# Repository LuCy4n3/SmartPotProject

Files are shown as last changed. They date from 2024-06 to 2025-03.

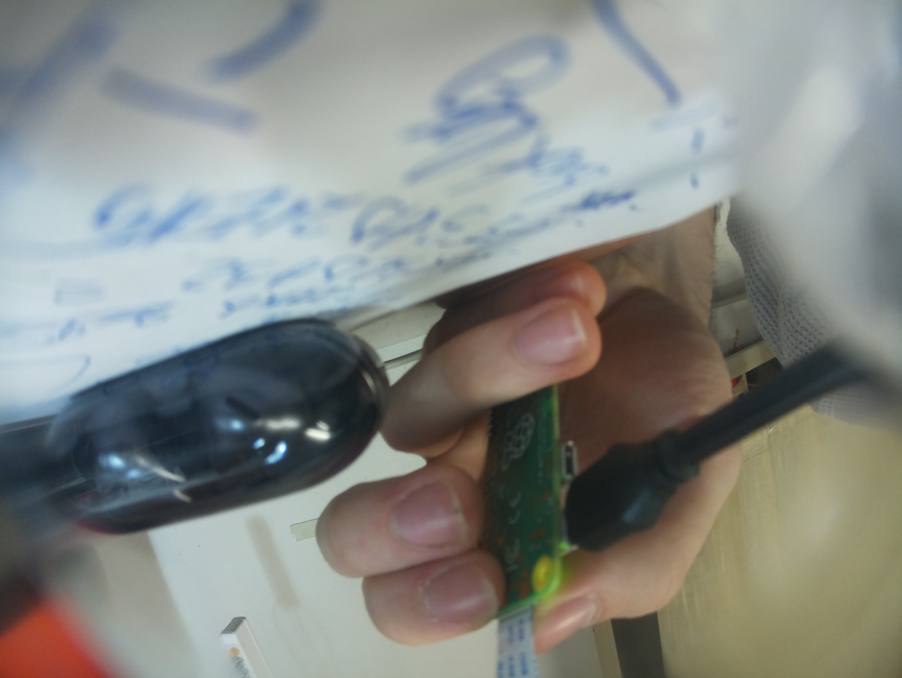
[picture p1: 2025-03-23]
SQLserverFinale/SQLserverFinale/wwwroot/images/test.jpg

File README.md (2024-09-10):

This are all the apps required, except Programmer I didn't code that, for the SmartPot PCB too work with the app GreenGrowApp. For this apps to run locally it is required to change the launchSettings file on both .NET apps and changing the URLs in the android app.

This is the link to proof of concept video: https://www.youtube.com/watch?v=sH559vDkE20&t=21s&ab_channel=RaulSimonca

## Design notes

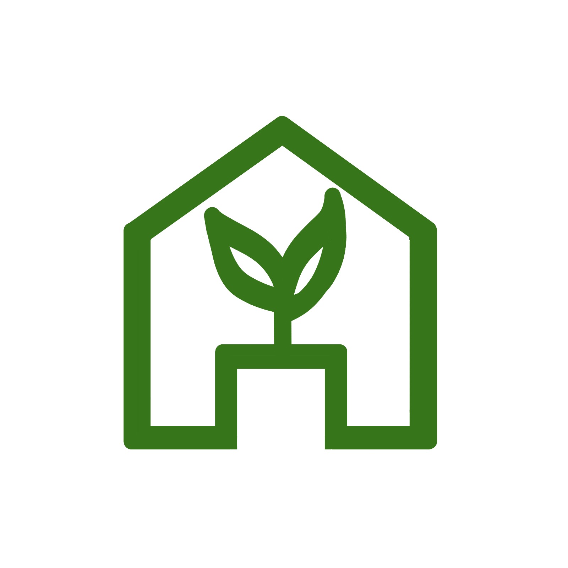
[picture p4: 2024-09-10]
pictApp.jpg

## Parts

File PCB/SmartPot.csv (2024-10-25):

Reference | Value | Datasheet | Footprint | Qty | DNP
C1,C4,Cbst1 | 100nF | ~ | -- mixed values -- | 3
C2 | 0.1uF | ~ | Capacitor_SMD:C_1206_3216Metric | 1
C3,Cin1,Cin2 | 10uF | ~ | -- mixed values -- | 3
C5 | 1uF | ~ | Capacitor_SMD:C_1206_3216Metric | 1
Cout1 | 47uF | ~ | Capacitor_SMD:C_1206_3216Metric_Pad1.33x1.80mm_HandSolder | 1
D1 | SM712_SOT23 | https://www.littelfuse.com/~/media/electronics/datasheets/tvs_diode_arrays/littelfuse_tvs_diode_array_sm712_datasheet.pdf.pdf | Package_TO_SOT_SMD:SOT-23 | 1
D2 | 1N4148W | https://www.vishay.com/docs/85748/1n4148w.pdf | Diode_SMD:D_SOD-123 | 1
D3 | LED | ~ | LED_THT:LED_D3.0mm_FlatTop | 1
F1 | Fuse | ~ | Fuse:Fuse_1206_3216Metric | 1
J1,J2 | Screw_Terminal_01x02 | ~ | TerminalBlock:TerminalBlock_bornier-2_P5.08mm | 2
J3,J5 | Conn_01x03_Pin | ~ | Connector_PinHeader_2.54mm:PinHeader_1x03_P2.54mm_Vertical | 2
J4 | Barrel_Jack_MountingPin | ~ | Connector_BarrelJack:BarrelJack_Kycon_KLDX-0202-xC_Horizontal | 1
J6 | Conn_01x04_Pin | ~ | Connector_PinHeader_2.54mm:PinHeader_1x04_P2.54mm_Vertical | 1
J7,J8 | Conn_01x02_Pin | ~ | Connector_PinHeader_2.54mm:PinHeader_1x02_P2.54mm_Vertical | 2
J9 | Screw_Terminal_01x04 | ~ | TerminalBlock_Altech:Altech_AK100_1x04_P5.00mm | 1
K1 | AWHSH112DM00G |  | Relay_THT:AWHSH112DM00G | 1
L1 | 4.7uH | ~ | Inductor_SMD:L_6.8x6.8_H3 | 1
Q1 | SSM3J352F_LF |  | Package_S-Mini:S-MINI_TOS | 1
R1,R2,R12,Rfbb1 | 10kOhm | ~ | -- mixed values -- | 4
R3,R4 | 10Ohm | ~ | Resistor_SMD:R_1210_3225Metric | 2
R5 | 120 | ~ | Resistor_SMD:R_1206_3216Metric | 1
R6,R7,R8,R9 | R_Photo | ~ | OptoDevice:R_LDR_4.9x4.2mm_P2.54mm_Vertical | 4
R10 | 10kohm | ~ | Resistor_SMD:R_1206_3216Metric_Pad1.30x1.75mm_HandSolder | 1
R11,R13,Rfbt1 | 56.2kOhm | ~ | -- mixed values -- | 3
R14,R15 | 20kOhm | ~ | Resistor_SMD:R_1206_3216Metric_Pad1.30x1.75mm_HandSolder | 2
R16 | 250-400 Ohm | ~ | Resistor_SMD:R_1206_3216Metric | 1
U1 | TPS561208DDCT |  | Converter_DCDC:SOT95P280X110-6N | 1
U2 | ADC084S021CIMM/NOPB | ADC084S021CIMM/NOPB | Package_SO:VSSOP-10_3x3mm_P0.5mm | 1
U3 | ULN2003A | http://www.ti.com/lit/ds/symlink/uln2003a.pdf | Package_SO:SOIC-16W_5.3x10.2mm_P1.27mm | 1
U4 | THVD1400D | https://www.ti.com/lit/ds/symlink/thvd1420.pdf | Package_SO:SOIC-8_3.9x4.9mm_P1.27mm | 1
U5 | AVR32DA32x-xPT | https://ww1.microchip.com/downloads/en/DeviceDoc/AVR32DA28-32-48-Data-Sheet-40002228B.pdf | Package_QFP:TQFP-32_7x7mm_P0.8mm | 1
U6 | SHT31A-DIS | https://www.sensirion.com/fileadmin/user_upload/customers/sensirion/Dokumente/2_Humidity_Sensors/Datasheets/Sensirion_Humidity_Sensors_SHT3xA_Datasheet.pdf | Sensor_Humidity:Sensirion_DFN-8-1EP_2.5x2.5mm_P0.5mm_EP1.1x1.7mm | 1
U7,U8 | ~ |  | -- mixed values -- | 2

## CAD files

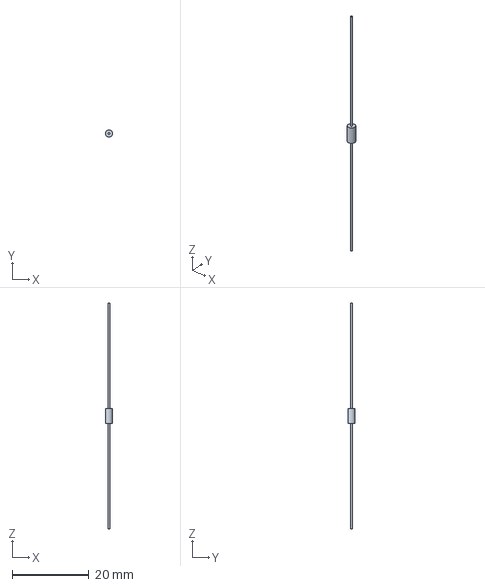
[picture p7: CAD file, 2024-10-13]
PCB/Components/1N4150/1N4150--3DModel-STEP-711646.STEP
1.90 x 1.90 x 58.9 mm

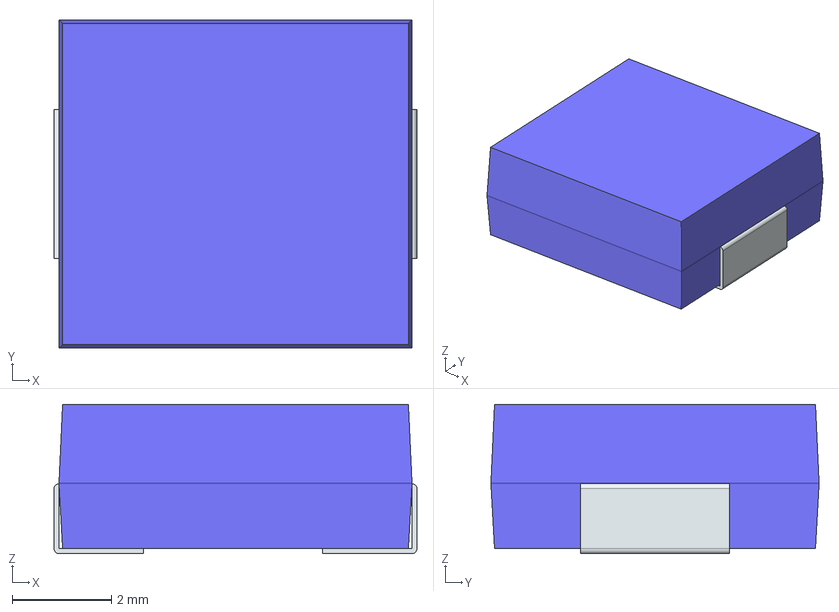
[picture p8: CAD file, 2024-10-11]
PCB/Components/Inductor/SRP7028CC-6R8M.stp
7.30 x 6.60 x 3.00 mm
FilletPin1
FilletPin2

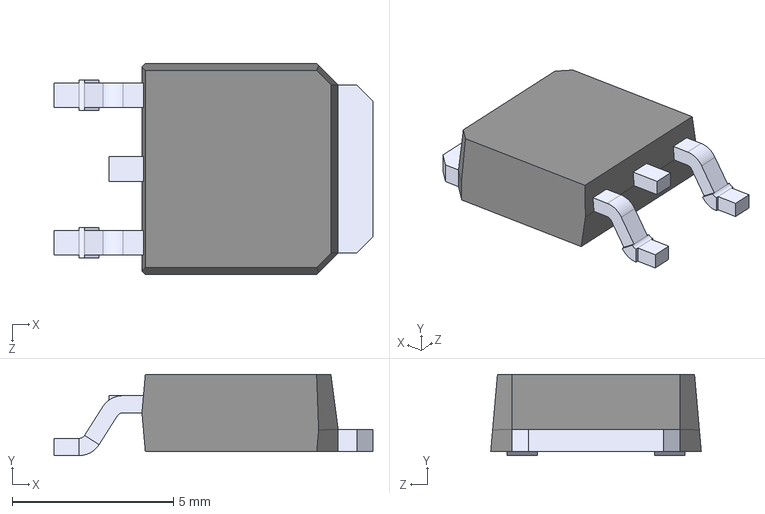
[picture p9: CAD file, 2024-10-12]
PCB/Components/IRFR5505/IRFR5505.step
9.91 x 2.52 x 6.54 mm

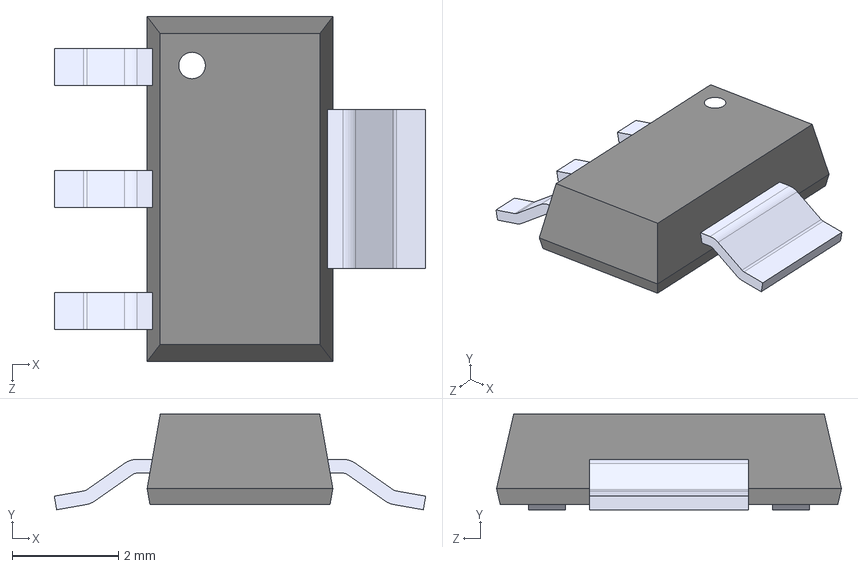
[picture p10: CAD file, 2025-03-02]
PCB/Components/LD1117S50TR/LD1117S50TR.step
7.00 x 1.80 x 6.50 mm

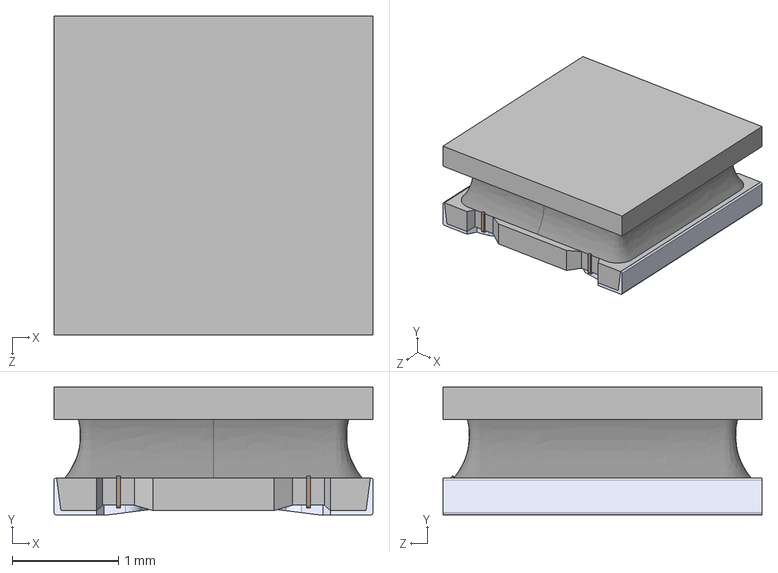
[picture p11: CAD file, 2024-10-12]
PCB/Components/LIB_SRP7028CC-6R8M/LQH3NPNR68NJRK.STEP
3.00 x 1.20 x 3.00 mm

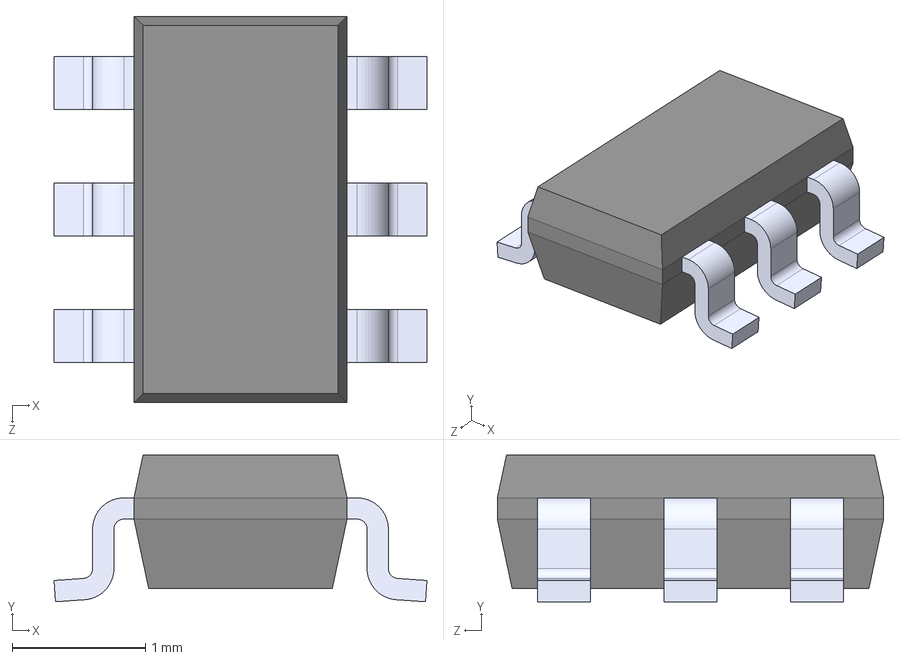
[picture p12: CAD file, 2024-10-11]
PCB/Components/TPS561208DDCT/TPS561208DDCT.step
2.80 x 1.10 x 2.90 mm

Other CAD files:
PCB/Components/LIB_SRP7028CC-6R8M/SRP7028CC-6R8M/Allegro/indpm7366x300n.psm
PCB/Components/LIB_SRP7028CC-6R8M/SRP7028CC-6R8M/DEHDL/srp7028cc_6r8m/chips/chips.prt

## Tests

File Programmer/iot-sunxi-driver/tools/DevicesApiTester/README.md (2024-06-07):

# DeviceApiTester

DeviceApiTester is a sample application primarily for testing the GPIO drivers and surrounding infrastructure.  After publishing the app to a target device, simply run `DeviceApiTester` to see the command line syntax.

One notable difference between the samples and real-world usage is that, because this sample allows for changing the GPIO driver from the command line, the base `GpioCommand` class has the `CreateGpioController` method. In practice, though, you would simply create the `GpioController` directly:

```csharp
using (var gpio = new GpioController())
{
    ...
}
```

Similarly, the same note applies to the SPI, I2C, and PWM test commands.

To simplify the command line parsing and adding new command, this application uses the
[CommandLineParser](https://github.com/commandlineparser/commandline) package. This simple parsing framework automatically creates help text based on attributes of the classes in the `Commands` folder, such as the `GpioBlinkLed` class.

Each of the commands has an `ExecuteAsync` or `Execute` method at the top of the class, which is where the sample usage is actually demonstrated. The automatic properties of the class represent options for the command, which are set by the command line parsing framework. The attributes on the command and its properties are used to setup the command line.

## Examples

1. See a list of all commands:<br/>
`DeviceApiTester help`

2. Show the `gpio-button-event` command's syntax:<br/>
`DeviceApiTester help gpio-button-event`

3. Run the command with required parameters:<br/>
`DeviceApiTester gpio-button-event --button-pin 5 --led-pin 6`

4. Run the command with many optional parameters:<br/>
`DeviceApiTester gpio-button-event --scheme Board --button-pin 29 --pressed-value Falling --led-pin 31 --on-value Low --driver RPi3`

5. Run the command with many optional parameters using single-characters options:<br/>
`DeviceApiTester gpio-button-event -s Board -b 29 -p Falling -l 31 --on-value Low -d RPi3`

## Adding Additional Commands

1. Derive a new class from one of the protocol base command classes, e.g., `GpioCommand`, `I2cCommand`, `SpiCommand`.  Deriving from one of these classes automatically gives your command the switches necessary to setup that type of connection.

    ```csharp
    namespace DeviceApiTester.Commands.I2c
    {
        public class MyCommand : I2cCommand
        {
        }
    }
    ```
    
    - It's easiest to begin by copying one of the existing commands.
    - Keep the new command class within the folder for connection type:<br/>
      `Commands/Gpio`, `Commands/I2c`, `Commands/Spi`.

2. Add or modify the `Verb` attribute to describe the command:
    ```csharp
    [Verb("i2c-my-command", HelpText = "This command does something with an I2C connection.")]
    ```
    - Prefix the command's verb with its connection type: `gpio-`, `i2c-`, `spi-`  

3. Implement either the `ICommandVerb` or `ICommandVerbAsync` interface on your command class:
    ```csharp
    public class MyCommand : I2cCommand, ICommandVerb
    {
        public int Execute()
        {
            Console.WriteLine($"BusId={BusId}, DeviceAddress={DeviceAddress}");
            return 0;
        }
    }
    ```
    or
    ```csharp
    public class MyCommand : I2cCommand, ICommandVerbAsync
    {
        public async Task<int> ExecuteAsync()
        {
            Console.WriteLine($"BusId={BusId}, DeviceAddress={DeviceAddress}");
            await Task.Delay(500);
            return 0;
        }
    }
    ```

4. Add automatic properties for command options:
    ```csharp
    [Option('c', "cool-option", HelpText = "A cool option argument", Required = false, Default = 0)]
    public int CoolOption { get; set; }
    ```

5. Use the properties in your execution:
    ```csharp
    public int Execute()
    {
        Console.WriteLine($"CoolOption={CoolOption}, BusId={BusId}, DeviceAddress={DeviceAddress}");
        ...
    }
    ```

6. Deploy and run:
    ```
    DeviceApiTester help
    DeviceApiTester help i2c-my-command
    DeviceApiTester i2c-my-command --cool-option 42
    ```

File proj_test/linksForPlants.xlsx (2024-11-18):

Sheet: completed
Daylilies | https://garden.org/plants/browse/plants/children/181473/
Irises | https://garden.org/plants/browse/plants/children/181474/
Roses | https://garden.org/plants/browse/plants/children/181506/
Sempervivum | https://garden.org/plants/browse/plants/children/186377/
Lilies | https://garden.org/plants/browse/plants/children/77555/
Hostas | https://garden.org/plants/browse/plants/children/181510/
Dahlias | https://garden.org/plants/browse/plants/children/76165/
Peonies | https://garden.org/plants/browse/plants/children/530825/
Daffodils | https://garden.org/plants/browse/plants/children/77916/
Tomatoes | https://garden.org/plants/browse/plants/children/77653/
Abelias | https://garden.org/plants/browse/plants/children/242735/
Abutilons | https://garden.org/plants/browse/plants/children/242733/
Adeniums | https://garden.org/plants/browse/plants/children/242253/
Aeoniums | https://garden.org/plants/browse/plants/children/649201/
Agapanthus | https://garden.org/plants/browse/plants/children/75143/
Agaves | https://garden.org/plants/browse/plants/children/242254/
Aglaonemas | https://garden.org/plants/browse/plants/children/71544/
Air Plants | https://garden.org/plants/browse/plants/children/232959/
Aloes | https://garden.org/plants/browse/plants/children/242252/
Amaryllis | https://garden.org/plants/browse/plants/children/76980/
Amorphophallus | https://garden.org/plants/browse/plants/children/243338/
Angel's Trumpets | https://garden.org/plants/browse/plants/children/236057/
Anise Hyssops | https://garden.org/plants/browse/plants/children/242700/
Anthuriums | https://garden.org/plants/browse/plants/children/538637/
Apples | https://garden.org/plants/browse/plants/children/86564/
Apricots | https://garden.org/plants/browse/plants/children/114689/
Arborvitaes | https://garden.org/plants/browse/plants/children/710373/
Arisaemas | https://garden.org/plants/browse/plants/children/528695/
Artichokes | https://garden.org/plants/browse/plants/children/87062/
Arums | https://garden.org/plants/browse/plants/children/641388/
Asparagus | https://garden.org/plants/browse/plants/children/86226/
Asters | https://garden.org/plants/browse/plants/children/232412/
Astilbes | https://garden.org/plants/browse/plants/children/242590/
Astragaluses | https://garden.org/plants/browse/plants/children/536504/
Baby's Breaths | https://garden.org/plants/browse/plants/children/126348/
Bananas | https://garden.org/plants/browse/plants/children/533137/
Baptisias | https://garden.org/plants/browse/plants/children/536505/
Barberries | https://garden.org/plants/browse/plants/children/240127/
Basils | https://garden.org/plants/browse/plants/children/588177/
Beans | https://garden.org/plants/browse/plants/children/86830/
Beautyberries | https://garden.org/plants/browse/plants/children/737439/
Bee Balms | https://garden.org/plants/browse/plants/children/242696/
Beets | https://garden.org/plants/browse/plants/children/530731/
Begonias | https://garden.org/plants/browse/plants/children/75518/
Bellflowers | https://garden.org/plants/browse/plants/children/528041/
Black Eyed Susans | https://garden.org/plants/browse/plants/children/78788/
Blanket Flowers | https://garden.org/plants/browse/plants/children/76606/
Bleeding Hearts | https://garden.org/plants/browse/plants/children/528113/
Blood Lilies | https://garden.org/plants/browse/plants/children/528285/
Bluebeards | https://garden.org/plants/browse/plants/children/528040/
Bluestem Grasses | https://garden.org/plants/browse/plants/children/528284/
Bougainvilleas | https://garden.org/plants/browse/plants/children/75569/
Brassicas | https://garden.org/plants/browse/plants/children/229759/
Butterfly Bushes | https://garden.org/plants/browse/plants/children/649002/
Butterworts | https://garden.org/plants/browse/plants/children/809714/
Caladiums | https://garden.org/plants/browse/plants/children/527355/
Calibrachoas | https://garden.org/plants/browse/plants/children/75655/
Callas | https://garden.org/plants/browse/plants/children/233380/
Camellias | https://garden.org/plants/browse/plants/children/75683/
Cannas | https://garden.org/plants/browse/plants/children/75726/
Cantaloupes | https://garden.org/plants/browse/plants/children/87175/
Cape Lilies | https://garden.org/plants/browse/plants/children/527558/
Cape Primroses | https://garden.org/plants/browse/plants/children/79113/
Carrots | https://garden.org/plants/browse/plants/children/386216/
Castor Beans | https://garden.org/plants/browse/plants/children/78747/
Catmints | https://garden.org/plants/browse/plants/children/242695/
Celeries | https://garden.org/plants/browse/plants/children/737487/
Chickweed | https://garden.org/plants/browse/plants/children/528417/
Chives | https://garden.org/plants/browse/plants/children/75204/
Chlorophytums | https://garden.org/plants/browse/plants/children/527545/
Chollas | https://garden.org/plants/browse/plants/children/232894/
Cilantros | https://garden.org/plants/browse/plants/children/86729/
Citrus Fruits | https://garden.org/plants/browse/plants/children/242635/
Clematis | https://garden.org/plants/browse/plants/children/181489/
Clivias | https://garden.org/plants/browse/plants/children/242628/
Colchicums | https://garden.org/plants/browse/plants/children/75960/
Coleus | https://garden.org/plants/browse/plants/children/79005/
Columbines | https://garden.org/plants/browse/plants/children/75302/
Coneflowers | https://garden.org/plants/browse/plants/children/185972/
Consolidas | https://garden.org/plants/browse/plants/children/646103/
Coral Bells | https://garden.org/plants/browse/plants/children/232967/
Corn | https://garden.org/plants/browse/plants/children/695646/
Cosmos | https://garden.org/plants/browse/plants/children/528112/
Crassulas | https://garden.org/plants/browse/plants/children/242255/
Crepe Myrtles | https://garden.org/plants/browse/plants/children/181507/
Crinums | https://garden.org/plants/browse/plants/children/76120/
Crocosmias | https://garden.org/plants/browse/plants/children/242597/
Crocus | https://garden.org/plants/browse/plants/children/242588/
Crotons | https://garden.org/plants/browse/plants/children/240116/
Cucumbers | https://garden.org/plants/browse/plants/children/546944/
Culinary Sages | https://garden.org/plants/browse/plants/children/4663/
Currants And Gooseberries | https://garden.org/plants/browse/plants/children/737497/
Dead Nettles | https://garden.org/plants/browse/plants/children/242648/
Delphiniums | https://garden.org/plants/browse/plants/children/76186/
Dianthus | https://garden.org/plants/browse/plants/children/76204/
Dieffenbachias | https://garden.org/plants/browse/plants/children/645466/
Dills | https://garden.org/plants/browse/plants/children/75274/
Dogwoods | https://garden.org/plants/browse/plants/children/527547/
Dracontiums | https://garden.org/plants/browse/plants/children/645122/
Dudleyas | https://garden.org/plants/browse/plants/children/242249/
Echeverias | https://garden.org/plants/browse/plants/children/117125/
Eggplants | https://garden.org/plants/browse/plants/children/87688/
Elephant Ears (Alocasia) | https://garden.org/plants/browse/plants/children/75214/
Elephant Ears (Colocasia) | https://garden.org/plants/browse/plants/children/242621/
Elephant Ears (Xanthosoma) | https://garden.org/plants/browse/plants/children/537490/
Epiphyllum | https://garden.org/plants/browse/plants/children/589130/
Erodiums | https://garden.org/plants/browse/plants/children/240734/
Erythroniums | https://garden.org/plants/browse/plants/children/536508/
Eupatoriums | https://garden.org/plants/browse/plants/children/536507/
Euphorbias | https://garden.org/plants/browse/plants/children/242586/
False Bananas | https://garden.org/plants/browse/plants/children/533136/
Figs | https://garden.org/plants/browse/plants/children/76528/
Foamflowers | https://garden.org/plants/browse/plants/children/229091/
Foamy Bells | https://garden.org/plants/browse/plants/children/232966/
Foxgloves | https://garden.org/plants/browse/plants/children/528115/
Freesias | https://garden.org/plants/browse/plants/children/76597/
Fritillarias | https://garden.org/plants/browse/plants/children/656551/
Fuchsias | https://garden.org/plants/browse/plants/children/76601/
Garden Nasturtiums | https://garden.org/plants/browse/plants/children/185903/
Gardenias | https://garden.org/plants/browse/plants/children/612276/
Garlic | https://garden.org/plants/browse/plants/children/75203/
Gayfeathers | https://garden.org/plants/browse/plants/children/536509/
Geraniums | https://garden.org/plants/browse/plants/children/233659/
Ginger Lilies | https://garden.org/plants/browse/plants/children/659229/
Gingers | https://garden.org/plants/browse/plants/children/659230/
Gladiolus | https://garden.org/plants/browse/plants/children/76715/
Goldenrods | https://garden.org/plants/browse/plants/children/527712/
Gourds, Squashes And Pumpkins | https://garden.org/plants/browse/plants/children/242703/
Grape Hyacinths | https://garden.org/plants/browse/plants/children/236410/
Grapes | https://garden.org/plants/browse/plants/children/706088/
Heavenly Bamboos | https://garden.org/plants/browse/plants/children/181462/
Hellebores | https://garden.org/plants/browse/plants/children/240735/
Hibiscus | https://garden.org/plants/browse/plants/children/242680/
Homalomenas | https://garden.org/plants/browse/plants/children/645477/
Honeysuckles | https://garden.org/plants/browse/plants/children/527546/
Hoyas | https://garden.org/plants/browse/plants/children/228342/
Hyacinths | https://garden.org/plants/browse/plants/children/527149/
Hydrangeas | https://garden.org/plants/browse/plants/children/232782/
Ilex | https://garden.org/plants/browse/plants/children/546842/
Joe Pye Weed | https://garden.org/plants/browse/plants/children/528424/
Jujubes | https://garden.org/plants/browse/plants/children/109204/
Kalanchoes | https://garden.org/plants/browse/plants/children/242256/
Lamb's Ears | https://garden.org/plants/browse/plants/children/703451/
Lantanas | https://garden.org/plants/browse/plants/children/664693/
Lavenders | https://garden.org/plants/browse/plants/children/238525/
Leeks | https://garden.org/plants/browse/plants/children/75202/
Lettuces | https://garden.org/plants/browse/plants/children/77401/
Ligularias | https://garden.org/plants/browse/plants/children/527803/
Lilacs | https://garden.org/plants/browse/plants/children/654247/
Lilies Of The Valley | https://garden.org/plants/browse/plants/children/242615/
Lions Tail | https://garden.org/plants/browse/plants/children/529791/
Liriopes | https://garden.org/plants/browse/plants/children/243264/
Living Stones | https://garden.org/plants/browse/plants/children/242239/
Lotuses | https://garden.org/plants/browse/plants/children/535523/
Magnolias | https://garden.org/plants/browse/plants/children/527354/
Maianthemums | https://garden.org/plants/browse/plants/children/243252/
Mammillarias | https://garden.org/plants/browse/plants/children/703749/
Mangoes | https://garden.org/plants/browse/plants/children/696302/
Marjorams | https://garden.org/plants/browse/plants/children/305608/
Melaleucas | https://garden.org/plants/browse/plants/children/741711/
Milkweeds | https://garden.org/plants/browse/plants/children/242659/
Mints | https://garden.org/plants/browse/plants/children/242686/
Mirabilis | https://garden.org/plants/browse/plants/children/242654/
Mock Oranges | https://garden.org/plants/browse/plants/children/716771/
Morning Glories | https://garden.org/plants/browse/plants/children/232852/
Nicotianas | https://garden.org/plants/browse/plants/children/242674/
Ninebarks | https://garden.org/plants/browse/plants/children/737437/
Nymphaeas | https://garden.org/plants/browse/plants/children/535524/
Oenotheras | https://garden.org/plants/browse/plants/children/242656/
Okra | https://garden.org/plants/browse/plants/children/87161/
Oleanders | https://garden.org/plants/browse/plants/children/71485/
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

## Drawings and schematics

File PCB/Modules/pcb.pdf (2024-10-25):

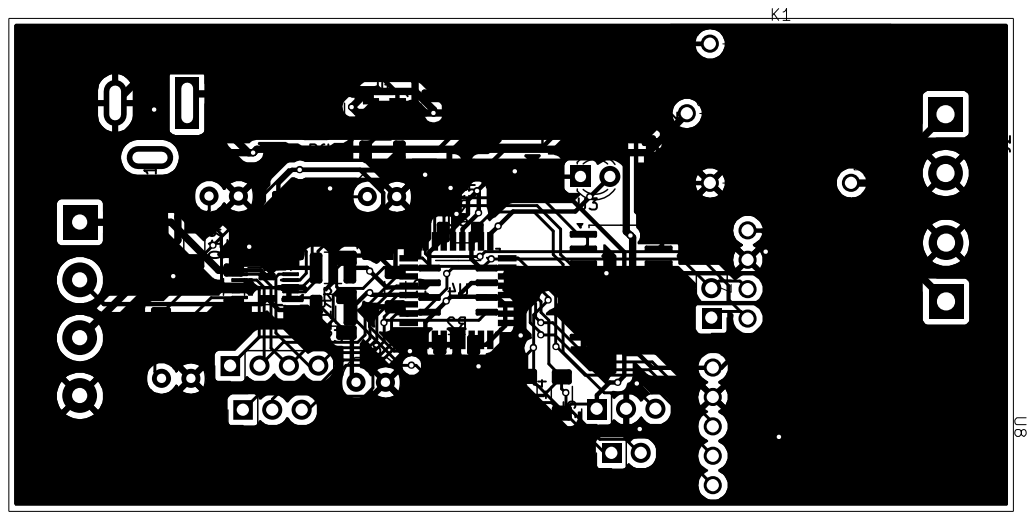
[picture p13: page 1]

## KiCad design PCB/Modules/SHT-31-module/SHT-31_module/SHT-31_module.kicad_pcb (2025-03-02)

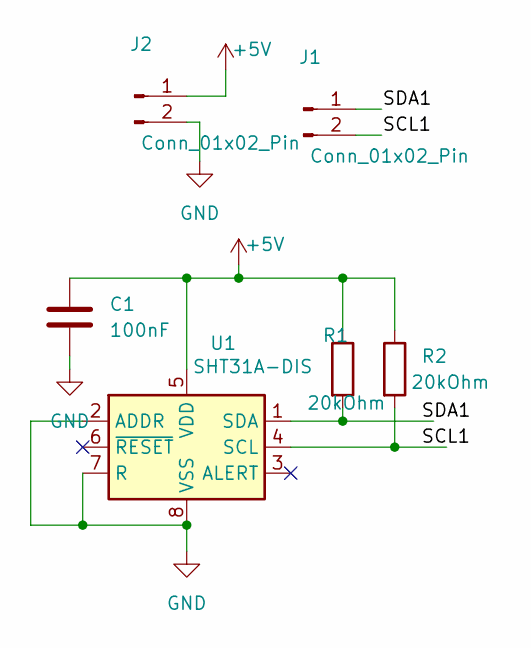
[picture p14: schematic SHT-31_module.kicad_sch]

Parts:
C1: 100nF; C_1206_3216Metric
J1, J2: Conn_01x02_Pin; PinHeader_1x02_P2.54mm_Vertical
R1, R2: 20kOhm; R_1206_3216Metric_Pad1.30x1.75mm_HandSolder
U1: SHT31A-DIS; Sensirion_DFN-8-1EP_2.5x2.5mm_P0.5mm_EP1.1x1.7mm

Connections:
+5V: C1.1, J2.1, R1.1, R2.1, U1.5 (VDD)
/SCL1: J1.2, R2.2, U1.4 (SCL)
/SDA1: J1.1, R1.2, U1.1 (SDA)
GND: C1.2, J2.2, U1.2 (ADDR), U1.7 (R), U1.8 (VSS), U1.9 (VSS)

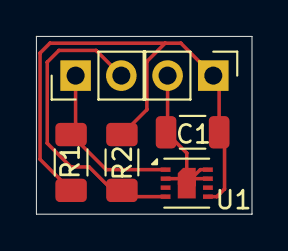
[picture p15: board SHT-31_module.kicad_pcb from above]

Board: 2 copper layers, 12.0 x 9.9 mm, 6 parts (0 on the bottom side), 4 nets.

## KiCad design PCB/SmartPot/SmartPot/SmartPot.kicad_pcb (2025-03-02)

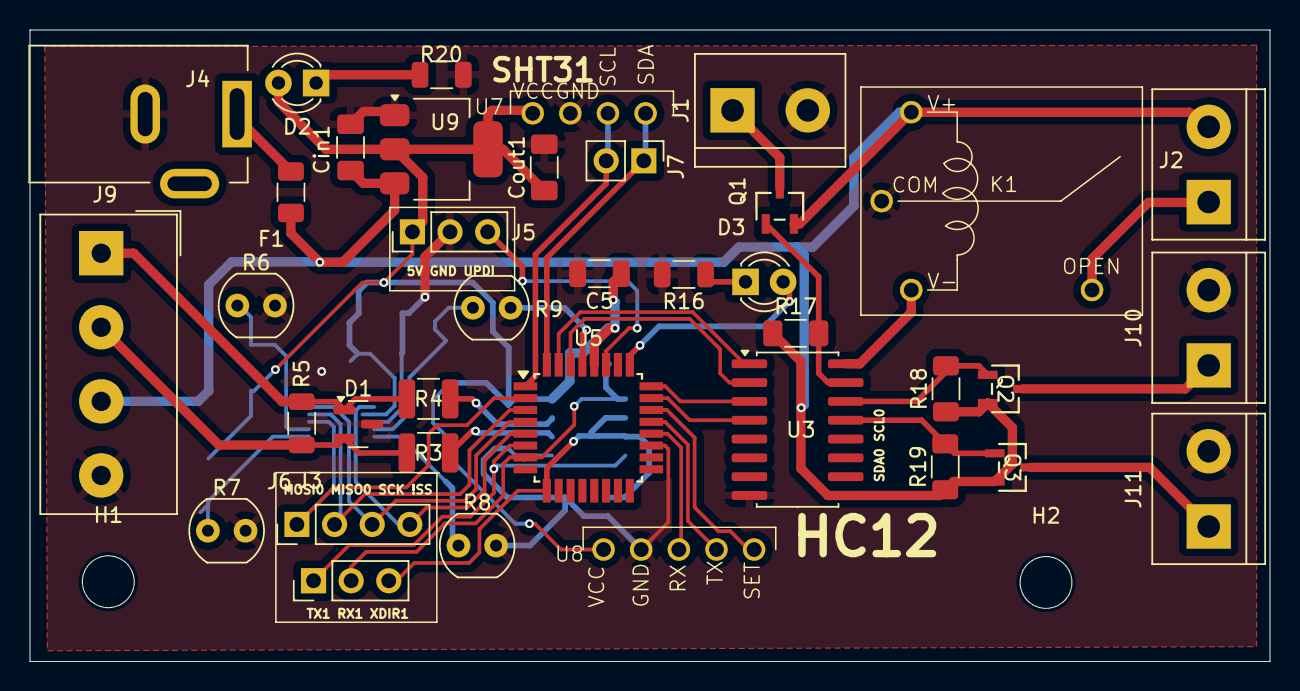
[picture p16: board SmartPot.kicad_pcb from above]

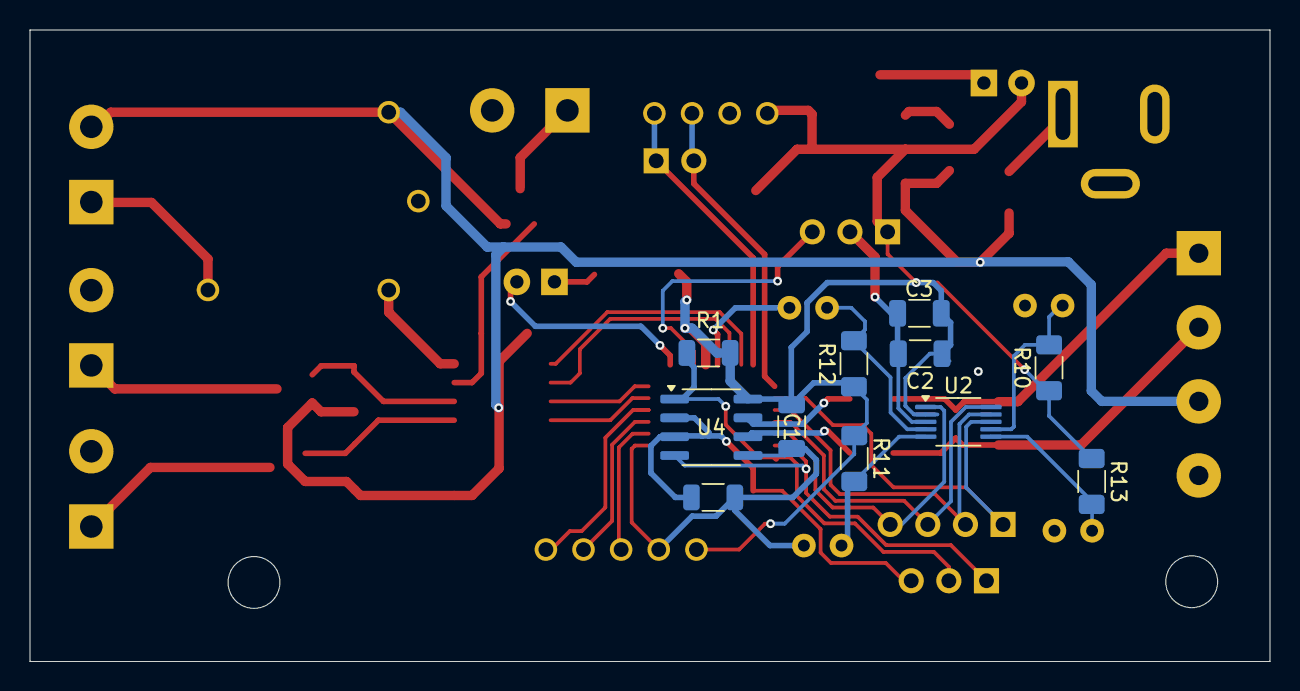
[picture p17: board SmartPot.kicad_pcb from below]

Board: 2 copper layers, 83.7 x 42.6 mm, 51 parts (11 on the bottom side), 40 nets.

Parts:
C1: 100nF; C_1206_3216Metric
C2: 0.1uF; C_1206_3216Metric
C3: 10uF; C_1206_3216Metric
C5: 1uF; C_1206_3216Metric
Cin1: 100nF; C_1206_3216Metric_Pad1.33x1.80mm_HandSolder
Cout1: 10uF; C_1206_3216Metric_Pad1.33x1.80mm_HandSolder
D1: SM712_SOT23; SOT-23
D2, D3: LED; LED_D3.0mm_FlatTop
F1: Fuse; Fuse_1206_3216Metric
H1, H2: MountingHole; MountingHole_3.5mm
J1, J2, J10, J11: Screw_Terminal_01x02; TerminalBlock_bornier-2_P5.08mm
J3, J5: Conn_01x03_Pin; PinHeader_1x03_P2.54mm_Vertical
J4: Barrel_Jack_MountingPin; BarrelJack_Kycon_KLDX-0202-xC_Horizontal
J6: Conn_01x04_Pin; PinHeader_1x04_P2.54mm_Vertical
J7: Conn_01x02_Pin; PinHeader_1x02_P2.54mm_Vertical
J9: Screw_Terminal_01x04; Altech_AK100_1x04_P5.00mm
K1: AWHSH112DM00G
Q1, Q2, Q3: SSM3J352F_LF; S-MINI_TOS
R1, R2: 10kOhm; R_1206_3216Metric
R3, R4: 10Ohm; R_1210_3225Metric
R5: 120; R_1206_3216Metric
R6, R7, R8, R9: R_Photo; R_LDR_4.9x4.2mm_P2.54mm_Vertical
R10, R17, R18, R19: 10kohm; R_1206_3216Metric_Pad1.30x1.75mm_HandSolder
R11, R13: 56.2kOhm; R_1206_3216Metric_Pad1.30x1.75mm_HandSolder
R12: 10kOhm; R_1206_3216Metric_Pad1.30x1.75mm_HandSolder
R16, R20: 250-400 Ohm; R_1206_3216Metric
U2: ADC084S021CIMM/NOPB; VSSOP-10_3x3mm_P0.5mm
U3: ULN2003A; SOIC-16W_5.3x10.2mm_P1.27mm
U4: THVD1400D; SOIC-8_3.9x4.9mm_P1.27mm
U5: AVR32DA32x-xPT; TQFP-32_7x7mm_P0.8mm
U7: SHT31-Module
U8: HC12-Modules
U9: LT1117-5.0; SOT-223-3_TabPin2

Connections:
+5V: C1.1, C2.1, C3.1, C5.1, Cout1.1, D2.2 (A), J5.1, R1.1, R10.1, R11.1, R12.1, R13.1, U2.2 (VA), U4.8 (VCC), U5.28 (VDD), U7.1 (VCC), U8.1 (VCC), U9.2 (VO)
+12V: Cin1.1, F1.1, J2.2, J9.3, K1.V+, Q1.2, Q2.2, Q3.2, R17.1, R18.1, R19.1, U3.9 (COM), U9.3 (VI)
/12Out: F1.2, J4.1
/!SS: J6.4, U2.1 (~CS), U5.5 (PA7)
/A: D1.2 (A2), J9.2, R3.2, R5.1
/Aout: R4.1, U4.7 (B)
/B: D1.1 (A1), J9.1, R4.2, R5.2
/Bout: R3.1, U4.6 (A)
/COMM1: U3.1 (I1), U5.31 (PA1)
/COMM2: U3.2 (I2), U5.30 (PA0)
/COMM3: U3.3 (I3), U5.24 (PF4)
/COMM4: U3.4 (I4), U5.23 (PF3)
/DIN: J6.1, U2.8 (DIN), U5.2 (PA4)
/IN1: R6.1, R10.2, U2.7 (IN1)
/IN2: R7.1, R13.2, U2.6 (IN2)
/IN3: R8.1, R11.2, U2.5 (IN3)
/IN4: R9.1, R12.2, U2.4 (IN4)
/LOAD1: J1.1, Q1.3
/LOAD2: J10.1, Q2.3
/LOAD3: J11.1, Q3.3
/MCLED: D3.2 (A), U5.25 (PF5)
/MISO0: J6.2, U2.9 (DOUT), U5.3 (PA5)
/OPEN: J2.1, K1.OPEN
/OUT1: K1.V-, U3.16 (O1)
/OUT2: Q1.1, R17.2, U3.15 (O2)
/OUT3: Q2.1, R18.2, U3.14 (O3)
/OUT4: Q3.1, R19.2, U3.13 (O4)
/RX1: J3.2, R1.2, U4.1 (RO), U5.7 (PC1)
/RX2: U5.21 (XTAL32K2/PF1), U8.4 (TX)
/SCK: J6.3, U2.10 (SCLK), U5.4 (PA6)
/SCL0: J7.2, U5.1 (PA3), U7.3 (SCL)
/SDA0: J7.1, U5.32 (PA2), U7.4 (SDA)
/SET: U5.22 (PF2), U8.5 (SET)
/TX1: J3.1, U4.4 (DI), U5.6 (PC0)
/TX2: U5.20 (XTAL32K1/PF0), U8.3 (RX)
/UPDI: J5.3, U5.27 (UPDI)
/XDIR1: J3.3, R2.1, U4.2 (~RE), U4.3 (DE), U5.9 (PC3)
GND: C1.2, C2.2, C3.2, C5.2, Cin1.2, Cout1.2, D1.3 (common), J1.2, J4.2, J5.2, J9.4, J10.2, J11.2, K1.COM, R2.2, R6.2, R7.2, R8.2, R9.2, R16.2, R20.2, U2.3 (GND), U3.8 (GND), U4.5 (GND), U5.19 (GND), U5.29 (GND), U7.2 (GND), U8.2 (GND), U9.1 (GND)
unnamed: D2.1 (K), R20.1
unnamed: D3.1 (K), R16.1

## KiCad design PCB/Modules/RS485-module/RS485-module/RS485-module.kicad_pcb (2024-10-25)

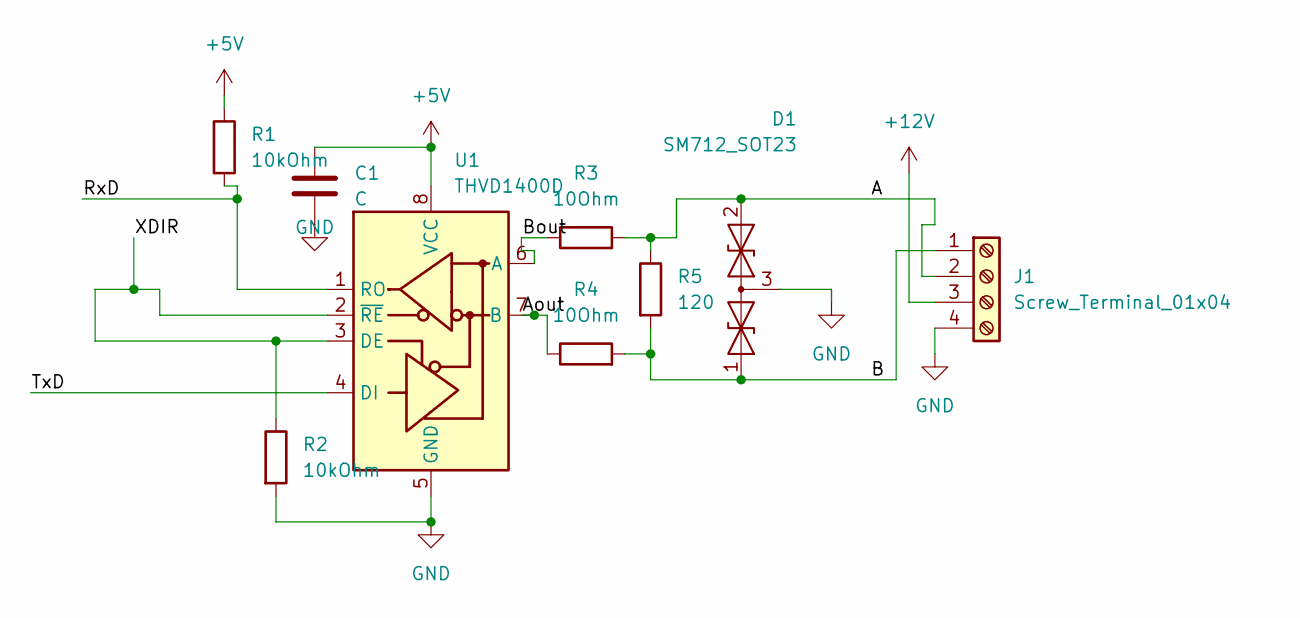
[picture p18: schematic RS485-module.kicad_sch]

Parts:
C1: C; C_1206_3216Metric
D1: SM712_SOT23; SOT-23
J1: Screw_Terminal_01x04; Altech_AK100_1x04_P5.00mm
R1, R2: 10kOhm; R_1206_3216Metric
R3, R4: 10Ohm; R_1210_3225Metric
R5: 120; R_1206_3216Metric
U1: THVD1400D; SOIC-8_3.9x4.9mm_P1.27mm

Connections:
+5V: C1.1, R1.1, U1.8 (VCC)
+12V: J1.3
/A: D1.2 (A2), J1.2, R3.2, R5.1
/Aout: R4.1, U1.7 (B)
/B: D1.1 (A1), J1.1, R4.2, R5.2
/Bout: R3.1, U1.6 (A)
/RxD: R1.2, U1.1 (RO)
/TxD: U1.4 (DI)
/XDIR: R2.1, U1.2 (~RE), U1.3 (DE)
GND: C1.2, D1.3 (common), J1.4, R2.2, U1.5 (GND)

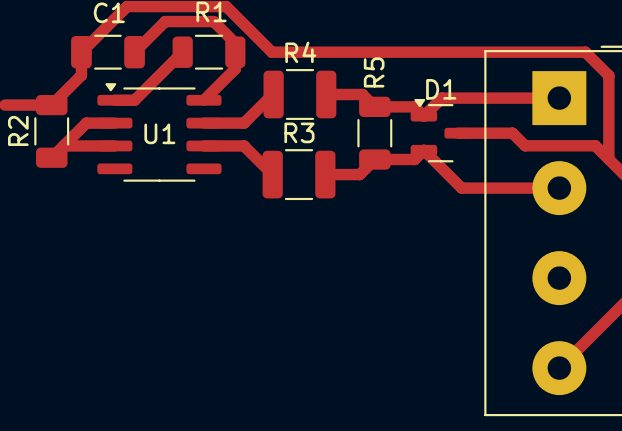
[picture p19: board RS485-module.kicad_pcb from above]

Board: 2 copper layers, 9 parts (0 on the bottom side), 8 nets.

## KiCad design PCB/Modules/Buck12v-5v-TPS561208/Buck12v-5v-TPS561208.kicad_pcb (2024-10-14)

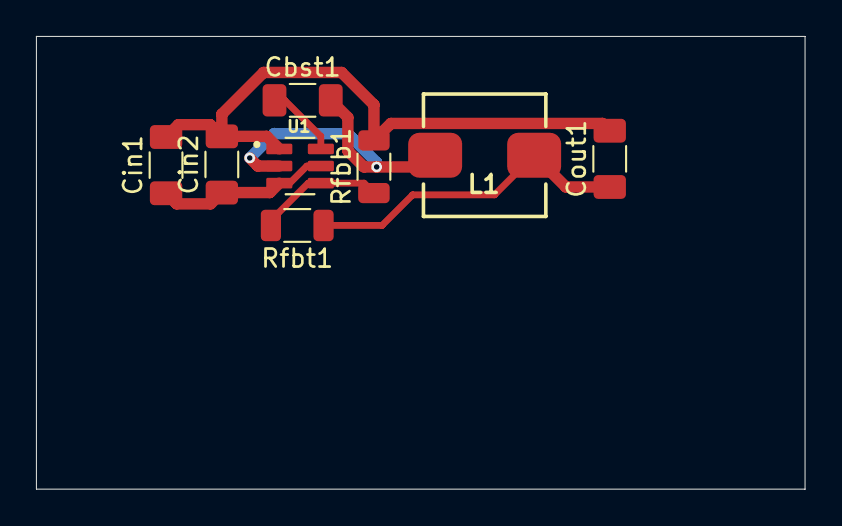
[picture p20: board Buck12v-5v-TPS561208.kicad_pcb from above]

Board: 2 copper layers, 42.7 x 25.2 mm, 8 parts (0 on the bottom side), 6 nets.

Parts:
Cbst1: 100nF; C_1206_3216Metric_Pad1.33x1.80mm_HandSolder
Cin1, Cin2: 10uF; C_1206_3216Metric_Pad1.33x1.80mm_HandSolder
Cout1: 47uF; C_1206_3216Metric_Pad1.33x1.80mm_HandSolder
L1: 4.7uH; L_6.8x6.8_H3
Rfbb1: 10kOhm; R_1206_3216Metric
Rfbt1: 56.2kOhm; R_1206_3216Metric
U1: TPS561208DDCT; SOT95P280X110-6N

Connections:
+5V: Cout1.1, L1.2, Rfbt1.1
+12V: Cin1.1, Cin2.1, U1.3 (VIN), U1.5 (EN)
/SW: Cbst1.2, L1.1, U1.2 (SW)
/VBST: Cbst1.1, U1.6 (VBST)
/VFB: Rfbb1.1, Rfbt1.2, U1.4 (VFB)
GND: Cin1.2, Cin2.2, Cout1.2, Rfbb1.2, U1.1 (GND)

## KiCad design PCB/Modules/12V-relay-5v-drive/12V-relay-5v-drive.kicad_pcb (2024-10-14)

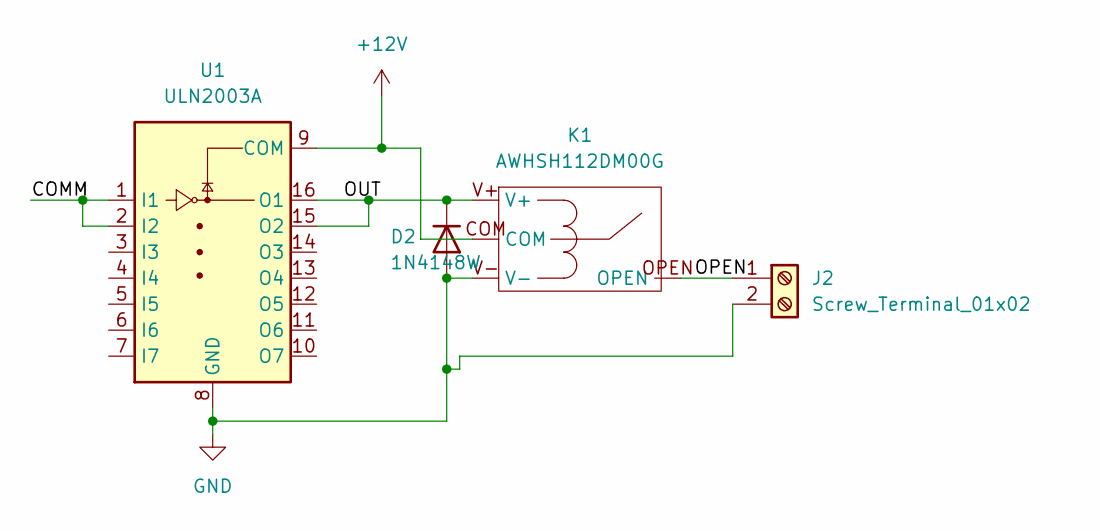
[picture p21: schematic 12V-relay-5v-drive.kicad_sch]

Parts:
D2: 1N4148W; D_SOD-123
J2: Screw_Terminal_01x02; TerminalBlock_bornier-2_P5.08mm
K1: AWHSH112DM00G
U1: ULN2003A; SOIC-16W_5.3x10.2mm_P1.27mm

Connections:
+12V: K1.COM, U1.9 (COM)
/COMM: U1.1 (I1), U1.2 (I2)
/OPEN: J2.1, K1.OPEN
/OUT: D2.1 (K), K1.V+, U1.15 (O2), U1.16 (O1)
GND: D2.2 (A), J2.2, K1.V-, U1.8 (GND)

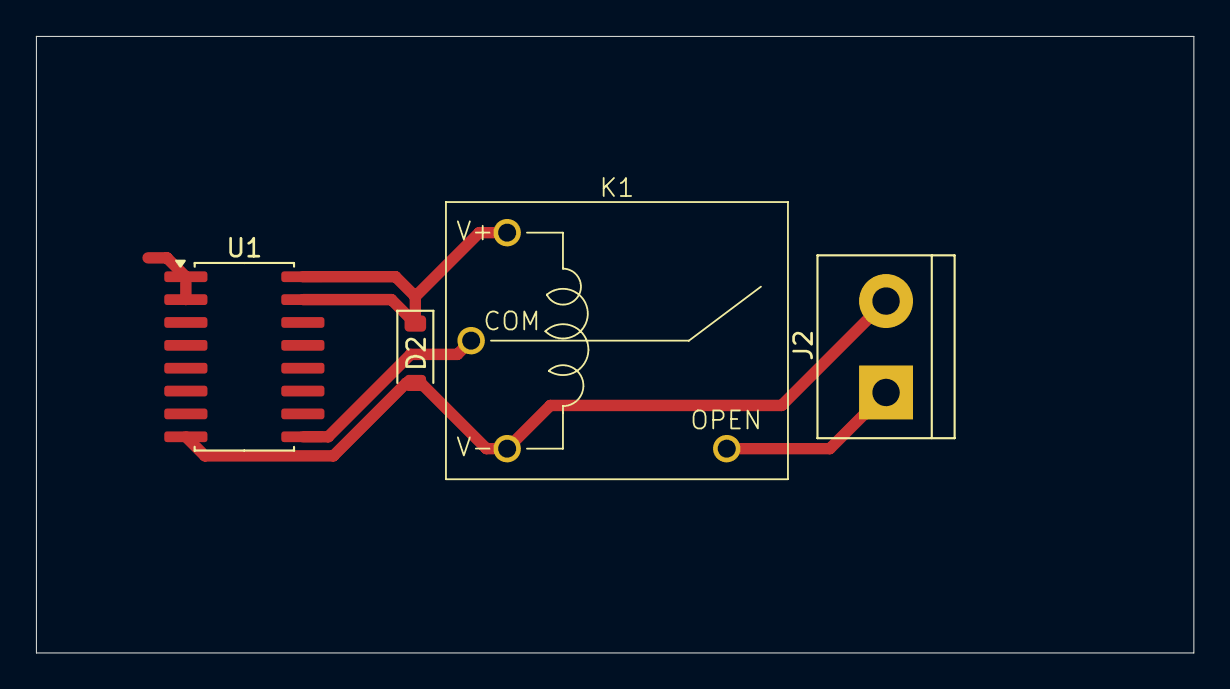
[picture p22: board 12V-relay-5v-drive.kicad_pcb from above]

Board: 2 copper layers, 64.3 x 34.2 mm, 4 parts (0 on the bottom side), 5 nets.

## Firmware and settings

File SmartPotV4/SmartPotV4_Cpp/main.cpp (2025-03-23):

/*
 * SmartPotV4_Cpp.cpp
 *
 * Created: 1/5/2025 10:15:57 PM
 * Author : simon
 */ 

#include <avr/io.h>
#include <atmel_start.h>
#include <util/delay.h>
#include <smartpot/CallbackFun.h>
#include "MyCode/Sensors/SHT31.h"
#define INDEX 4
#define TYPE 2

static uint8_t *bufferToSend;
static uint8_t *bufferToRead;

void serialWrite(uint8_t* data,uint8_t length)
{
	for(uint8_t i = 0;i<length;i++)
	{
		writeOneByte(data[i]);
	}
}

void serialPrint(uint8_t* data)
{
	uint8_t idx = 0;
	while(data[idx]!=0)
	{
		writeOneByte(data[idx]);
		idx++;
	}
}

void serialPrintConst(const char* data)
{
	serialPrint((uint8_t*)data);
}

void serialPrintLn(const char* data)
{
	serialPrint((uint8_t*)data);
	serialPrint((uint8_t*)"\r\n");
}

void serialPrintNumber(int nr)
{
	char strBuff[8];
	for(uint8_t i = 0;i<8;i++)
	{
		strBuff[i] = 0;
	}
	itoa(nr,strBuff,10);
	serialPrint((uint8_t*)strBuff);
}
void SerialWrite(const char* data)
{
	uint8_t* pData = (uint8_t*)data;
	while(*pData!=0)
	{
		USART_RADIO_write(*pData);
		pData++;
		//while(!USART1_IsTxReady());
	}
}

void enableSPI_soft()
{
	PORTA_set_pin_dir(4,PORT_DIR_OUT);	// MOSI
	PORTA_set_pin_dir(5,PORT_DIR_IN);	// MISO
	PORTA_set_pin_dir(6,PORT_DIR_OUT);	// SCK
	PORTA_set_pin_dir(7,PORT_DIR_OUT);	// !SS
	
	PORTA_set_pin_level(4,false);		// set the MOSI low
	PORTA_set_pin_level(5,false);		// set the MISO low
	PORTA_set_pin_level(6,false);		// set the starting position of the clock to low
	PORTA_set_pin_level(7,true);		// set the SS high
	
}
bool converToBool(uint8_t number) {
	return number >= 1 ? true : false;
}
void newClock(uint8_t pin)
{
	PORTA_set_pin_level(6,converToBool(!PORTA_get_pin_level(6)));
	_delay_ms(100);
	PORTA_set_pin_level(6,converToBool(!PORTA_get_pin_level(6)));
	_delay_ms(100);
}
uint8_t readSpiADC(uint8_t channel)
{
	uint8_t readData = 0;
	bool setState;
	//channel = channel << 1; // make sure the actual data that can be between 0 and 3, is placed in the bits that are of interest
	//write
	PORTA_set_pin_level(6,false);
	PORTA_set_pin_level(7,false);
	PORTA_set_pin_level(4,false);
	//_delay_ms(100);
	//PORTA_set_pin_level(6,true);
	//_delay_ms(100);
	//PORTA_set_pin_level(6,false);
	//_delay_ms(100);
	//PORTA_set_pin_level(6,true);
	//_delay_ms(100);
	newClock(6);
	//newClock(6);
	//writeOneByte(0xA);
	for(uint8_t i = 7; i > 0; i--)
	{
		
		//PORTA_toggle_pin_level(6);
		PORTA_set_pin_level(4,converToBool(channel&(1<<i)));
		_delay_ms(20);
		newClock(6);
		//PORTA_toggle_pin_level(4);
		
		//setState = i<=2 ? true : false;
		//PORTA_set_pin_level(4,setState);
		//writeOneByte(converToBool(channel&(1<<aux)) == true? 1 : 0);
		readData = (readData<<1) | PORTA_get_pin_level(5);
		//writeOneByte(readData);
		//writeOneByte(PORTA_get_pin_level(5));
		//_delay_ms(100);
	}
	//_delay_ms(100);
	PORTA_set_pin_level(4,false);
	
	//writeOneByte(0xC);
	
	//readData = PORTA_get_pin_level(5);
	//read
	//_delay_ms(200);
	for(uint8_t i = 0; i < 4; i++)
	{
		//PORTA_toggle_pin_level(6);
		newClock(6);
		readData = (readData<<1) | PORTA_get_pin_level(5);
		//writeOneByte(PORTA_get_pin_level(5));
		//writeOneByte(readData);
		//_delay_ms(100);
	}
	//writeOneByte(0xA);
	PORTA_set_pin_level(7,true);
	return readData;
	
}
void headerHandler(uint8_t utilityId)
{
	writeOneByte(15);
	writeOneByte(INDEX);
	writeOneByte(TYPE);
	writeOneByte(utilityId);
}
void sendTemp(int32_t readTemp,uint8_t utilityId)
{
	uint8_t* tempBytes = (uint8_t*)&readTemp;
	headerHandler(utilityId);
	serialPrint(tempBytes);
}
void sendHum(uint32_t readHum,uint8_t utilityId)
{
	uint8_t* humBytes = (uint8_t*)&readHum;
	headerHandler(utilityId);
	serialPrint(humBytes);
}

SHT31Class SHT31;

int main(void)
{
	/* Initializes MCU, drivers and middleware */
	atmel_start_init();
	PWM_LED_init();
	PWM_LED_enable();
	PWM_0_init();
	PWM_0_enable();
	PWM_0_load_top(0xff);
	PWM_0_enable_output_ch0();
	USART_RADIO_enable();
	initCB();
	I2C_Module_init();
	
	_delay_us(50);
	int32_t temp,hum;
	uint16_t errorCode;
	
	//serialWrite((uint8_t*)temp,4);
	USART_RADIO_set_ISR_cb(&newCbTx,UDRE_CB);
	USART_RADIO_set_ISR_cb(&newCbRx,RX_CB);
	//errorCode = SHT31.readBoth(temp,hum);
	writeOneByte(0xA);
	enableSPI_soft();
	/* Replace with your application code */
	PORTF_set_pin_dir(5,PORT_DIR_OUT);
	PORTF_set_pin_dir(3,PORT_DIR_OUT);
	PORTA_set_pin_dir(1,PORT_DIR_OUT);
	PORTA_set_pin_level(1,false);
	PWM_LED_load_duty_cycle_ch0(0x0);
	PWM_0_load_duty_cycle_ch0(0x0);
	//PWM_0_load_duty_cycle_ch0(0xf);
	errorCode = SHT31.begin(0x44);	
	//TIMER_0_enable();
	while (1) {
		PORTF_set_pin_level(5,true);
		errorCode = SHT31.begin(0x44);
		//writeOneByte(errorCode<<8);
		//writeOneByte(errorCode);
		errorCode = SHT31.readBoth(&temp,&hum);
		sendTemp(temp,1);
		_delay_ms(1000);
		sendHum(hum,2);
		//PORTF_set_pin_level(3,true);
		//writeOneByte(0xB);
		//readSpiADC(0);
		_delay_ms(1000);
		PORTF_set_pin_level(5,false);
		//PORTF_set_pin_level(3,false);
		_delay_ms(1000);
		//writeOneByte(readSpiADC(0xFF));
	}
}

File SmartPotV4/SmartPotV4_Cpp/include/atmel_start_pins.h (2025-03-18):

/*
 * Code generated from START.
 *
 * This file will be overwritten when reconfiguring your START project.
 * Please copy examples or other code you want to keep to a separate file
 * to avoid losing it when reconfiguring.
 */
#ifndef ATMEL_START_PINS_H_INCLUDED
#define ATMEL_START_PINS_H_INCLUDED

#include <port.h>

/**
 * \brief Set PA0 pull mode
 *
 * Configure pin to pull up, down or disable pull mode, supported pull
 * modes are defined by device used
 *
 * \param[in] pull_mode Pin pull mode
 */
static inline void PA0_set_pull_mode(const enum port_pull_mode pull_mode)
{
	PORTA_set_pin_pull_mode(0, pull_mode);
}

/**
 * \brief Set PA0 data direction
 *
 * Select if the pin data direction is input, output or disabled.
 * If disabled state is not possible, this function throws an assert.
 *
 * \param[in] direction PORT_DIR_IN  = Data direction in
 *                      PORT_DIR_OUT = Data direction out
 *                      PORT_DIR_OFF = Disables the pin
 *                      (low power state)
 */
static inline void PA0_set_dir(const enum port_dir dir)
{
	PORTA_set_pin_dir(0, dir);
}

/**
 * \brief Set PA0 input/sense configuration
 *
 * Enable/disable PA0 digital input buffer and pin change interrupt,
 * select pin interrupt edge/level sensing mode
 *
 * \param[in] isc PORT_ISC_INTDISABLE_gc    = Iterrupt disabled but input buffer enabled
 *                PORT_ISC_BOTHEDGES_gc     = Sense Both Edges
 *                PORT_ISC_RISING_gc        = Sense Rising Edge
 *                PORT_ISC_FALLING_gc       = Sense Falling Edge
 *                PORT_ISC_INPUT_DISABLE_gc = Digital Input Buffer disabled
 *                PORT_ISC_LEVEL_gc         = Sense low Level
 */
static inline void PA0_set_isc(const PORT_ISC_t isc)
{
	PORTA_pin_set_isc(0, isc);
}

/**
 * \brief Set PA0 inverted mode
 *
 * Enable or disable inverted I/O on a pin
 *
 * \param[in] inverted true  = I/O on PA0 is inverted
 *                     false = I/O on PA0 is not inverted
 */
static inline void PA0_set_inverted(const bool inverted)
{
	PORTA_pin_set_inverted(0, inverted);
}

/**
 * \brief Set PA0 level
 *
 * Sets output level on a pin
 *
 * \param[in] level true  = Pin level set to "high" state
 *                  false = Pin level set to "low" state
 */
static inline void PA0_set_level(const bool level)
{
	PORTA_set_pin_level(0, level);
}

/**
 * \brief Toggle output level on PA0
 *
 * Toggle the pin level
 */
static inline void PA0_toggle_level()
{
	PORTA_toggle_pin_level(0);
}

/**
 * \brief Get level on PA0
 *
 * Reads the level on a pin
 */
static inline bool PA0_get_level()
{
	return PORTA_get_pin_level(0);
}

/**
 * \brief Set PA2 pull mode
 *
 * Configure pin to pull up, down or disable pull mode, supported pull
 * modes are defined by device used
 *
 * \param[in] pull_mode Pin pull mode
 */
static inline void PA2_set_pull_mode(const enum port_pull_mode pull_mode)
{
	PORTA_set_pin_pull_mode(2, pull_mode);
}

/**
 * \brief Set PA2 data direction
 *
 * Select if the pin data direction is input, output or disabled.
 * If disabled state is not possible, this function throws an assert.
 *
 * \param[in] direction PORT_DIR_IN  = Data direction in
 *                      PORT_DIR_OUT = Data direction out
 *                      PORT_DIR_OFF = Disables the pin
 *                      (low power state)
 */
static inline void PA2_set_dir(const enum port_dir dir)
{
	PORTA_set_pin_dir(2, dir);
}

/**
 * \brief Set PA2 input/sense configuration
 *
 * Enable/disable PA2 digital input buffer and pin change interrupt,
 * select pin interrupt edge/level sensing mode
 *
 * \param[in] isc PORT_ISC_INTDISABLE_gc    = Iterrupt disabled but input buffer enabled
 *                PORT_ISC_BOTHEDGES_gc     = Sense Both Edges
 *                PORT_ISC_RISING_gc        = Sense Rising Edge
 *                PORT_ISC_FALLING_gc       = Sense Falling Edge
 *                PORT_ISC_INPUT_DISABLE_gc = Digital Input Buffer disabled
 *                PORT_ISC_LEVEL_gc         = Sense low Level
 */
static inline void PA2_set_isc(const PORT_ISC_t isc)
{
	PORTA_pin_set_isc(2, isc);
}

/**
 * \brief Set PA2 inverted mode
 *
 * Enable or disable inverted I/O on a pin
 *
 * \param[in] inverted true  = I/O on PA2 is inverted
 *                     false = I/O on PA2 is not inverted
 */
static inline void PA2_set_inverted(const bool inverted)
{
	PORTA_pin_set_inverted(2, inverted);
}

/**
 * \brief Set PA2 level
 *
 * Sets output level on a pin
 *
 * \param[in] level true  = Pin level set to "high" state
 *                  false = Pin level set to "low" state
 */
static inline void PA2_set_level(const bool level)
{
	PORTA_set_pin_level(2, level);
}

/**
 * \brief Toggle output level on PA2
 *
 * Toggle the pin level
 */
static inline void PA2_toggle_level()
{
	PORTA_toggle_pin_level(2);
}

/**
 * \brief Get level on PA2
 *
 * Reads the level on a pin
 */
static inline bool PA2_get_level()
{
	return PORTA_get_pin_level(2);
}

/**
 * \brief Set PA3 pull mode
 *
 * Configure pin to pull up, down or disable pull mode, supported pull
 * modes are defined by device used
 *
 * \param[in] pull_mode Pin pull mode
 */
static inline void PA3_set_pull_mode(const enum port_pull_mode pull_mode)
{
	PORTA_set_pin_pull_mode(3, pull_mode);
}

/**
 * \brief Set PA3 data direction
 *
 * Select if the pin data direction is input, output or disabled.
 * If disabled state is not possible, this function throws an assert.
 *
 * \param[in] direction PORT_DIR_IN  = Data direction in
 *                      PORT_DIR_OUT = Data direction out
 *                      PORT_DIR_OFF = Disables the pin
 *                      (low power state)
 */
static inline void PA3_set_dir(const enum port_dir dir)
{
	PORTA_set_pin_dir(3, dir);
}

/**
 * \brief Set PA3 input/sense configuration
 *
 * Enable/disable PA3 digital input buffer and pin change interrupt,
 * select pin interrupt edge/level sensing mode
 *
 * \param[in] isc PORT_ISC_INTDISABLE_gc    = Iterrupt disabled but input buffer enabled
 *                PORT_ISC_BOTHEDGES_gc     = Sense Both Edges
 *                PORT_ISC_RISING_gc        = Sense Rising Edge
 *                PORT_ISC_FALLING_gc       = Sense Falling Edge
 *                PORT_ISC_INPUT_DISABLE_gc = Digital Input Buffer disabled
 *                PORT_ISC_LEVEL_gc         = Sense low Level
 */
static inline void PA3_set_isc(const PORT_ISC_t isc)
{
	PORTA_pin_set_isc(3, isc);
}

/**
 * \brief Set PA3 inverted mode
 *
 * Enable or disable inverted I/O on a pin
 *
 * \param[in] inverted true  = I/O on PA3 is inverted
 *                     false = I/O on PA3 is not inverted
 */
static inline void PA3_set_inverted(const bool inverted)
{
	PORTA_pin_set_inverted(3, inverted);
}
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

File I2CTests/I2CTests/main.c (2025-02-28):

#include <atmel_start.h>
#include <util/delay.h>

void SerialWrite(uint8_t* data)
{
	uint8_t* pData = data;
	while(*pData!=0)
	{
		USART_0_write(*pData);
		pData++;
		//while(!USART1_IsTxReady());
	}
}
int main(void)
{
	/* Initializes MCU, drivers and middleware */
	atmel_start_init();
	
	PORTA_set_pin_dir(4,PORT_DIR_OUT);
	/* Replace with your application code */
	while (1) {
		SerialWrite("Started 1");
		//USART_0_write('a');
		PORTA_set_pin_level(4,true);
		_delay_ms(1000);
		PORTA_set_pin_level(4,false);
		_delay_ms(1000);
	}
}

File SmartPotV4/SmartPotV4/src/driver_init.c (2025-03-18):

/**
 * \file
 *
 * \brief Driver initialization.
 *
 (c) 2020 Microchip Technology Inc. and its subsidiaries.

    Subject to your compliance with these terms,you may use this software and
    any derivatives exclusively with Microchip products.It is your responsibility
    to comply with third party license terms applicable to your use of third party
    software (including open source software) that may accompany Microchip software.

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
    IN NO EVENT WILL MICROCHIP BE LIABLE FOR ANY INDIRECT, SPECIAL, PUNITIVE,
    INCIDENTAL OR CONSEQUENTIAL LOSS, DAMAGE, COST OR EXPENSE OF ANY KIND
    WHATSOEVER RELATED TO THE SOFTWARE, HOWEVER CAUSED, EVEN IF MICROCHIP HAS
    BEEN ADVISED OF THE POSSIBILITY OR THE DAMAGES ARE FORESEEABLE. TO THE
    FULLEST EXTENT ALLOWED BY LAW, MICROCHIP'S TOTAL LIABILITY ON ALL CLAIMS IN
    ANY WAY RELATED TO THIS SOFTWARE WILL NOT EXCEED THE AMOUNT OF FEES, IF ANY,
    THAT YOU HAVE PAID DIRECTLY TO MICROCHIP FOR THIS SOFTWARE.
 *
 */

/*
 * Code generated by START.
 *
 * This file will be overwritten when reconfiguring your START project.
 * Please copy examples or other code you want to keep to a separate file
 * to avoid losing it when reconfiguring.
 */

#include "driver_init.h"
#include <system.h>

/* configure the pins and initialize the registers */
void USART_NPK_initialization(void)
{

	// Set pin direction to input
	PC1_set_dir(PORT_DIR_IN);

	PC1_set_pull_mode(
	    // <y> Pull configuration
	    // <id> pad_pull_config
	    // <PORT_PULL_OFF"> Off
	    // <PORT_PULL_UP"> Pull-up
	    PORT_PULL_OFF);

	// Set pin direction to output

	PC0_set_level(
	    // <y> Initial level
	    // <id> pad_initial_level
	    // <false"> Low
	    // <true"> High
	    false);

	PC0_set_dir(PORT_DIR_OUT);

	USART_NPK_init();
}

/* configure the pins and initialize the registers */
void USART_RADIO_initialization(void)
{

	// Set pin direction to input
	PF1_set_dir(PORT_DIR_IN);

	PF1_set_pull_mode(
	    // <y> Pull configuration
	    // <id> pad_pull_config
	    // <PORT_PULL_OFF"> Off
	    // <PORT_PULL_UP"> Pull-up
	    PORT_PULL_OFF);

	// Set pin direction to output

	PF0_set_level(
	    // <y> Initial level
	    // <id> pad_initial_level
	    // <false"> Low
	    // <true"> High
	    false);

	PF0_set_dir(PORT_DIR_OUT);

	USART_RADIO_init();
}

/* configure pins and initialize registers */
void I2C_Module_initialization(void)
{

	PA3_set_level(
	    // <y> Initial level
	    // <id> pad_initial_level
	    // <false"> Low
	    // <true"> High
	    false);

	PA3_set_dir(
	    // <y> Pin direction
	    // <id> pad_dir
	    // <PORT_DIR_OFF"> Off
	    // <PORT_DIR_IN"> In
	    // <PORT_DIR_OUT"> Out
	    PORT_DIR_OUT);

	PA3_set_pull_mode(
	    // <y> Pull configuration
	    // <id> pad_pull_config
	    // <PORT_PULL_OFF"> Off
	    // <PORT_PULL_UP"> Pull-up
	    PORT_PULL_OFF);

	PA3_set_inverted(
	    // <y> Invert I/O on pin
	    // <id> pad_invert
	    // <false"> Not inverted
	    // <true"> Inverted
	    false);

	PA3_set_isc(
	    // <y> Pin Input/Sense Configuration
	    // <id> pad_isc
	    // <PORT_ISC_INTDISABLE_gc"> Interrupt disabled but input buffer enabled
	    // <PORT_ISC_BOTHEDGES_gc"> Sense Both Edges
	    // <PORT_ISC_RISING_gc"> Sense Rising Edge
	    // <PORT_ISC_FALLING_gc"> Sense Falling Edge
	    // <PORT_ISC_INPUT_DISABLE_gc"> Digital Input Buffer disabled
	    // <PORT_ISC_LEVEL_gc"> Sense low Level
	    PORT_ISC_INTDISABLE_gc);

	/* set the alternate pin mux */

	PA2_set_level(
	    // <y> Initial level
	    // <id> pad_initial_level
	    // <false"> Low
	    // <true"> High
	    false);

	PA2_set_dir(
	    // <y> Pin direction
	    // <id> pad_dir
	    // <PORT_DIR_OFF"> Off
	    // <PORT_DIR_IN"> In
	    // <PORT_DIR_OUT"> Out
	    PORT_DIR_OUT);

	PA2_set_pull_mode(
	    // <y> Pull configuration
	    // <id> pad_pull_config
	    // <PORT_PULL_OFF"> Off
	    // <PORT_PULL_UP"> Pull-up
	    PORT_PULL_OFF);

	PA2_set_inverted(
	    // <y> Invert I/O on pin
	    // <id> pad_invert
	    // <false"> Not inverted
	    // <true"> Inverted
	    false);

	PA2_set_isc(
	    // <y> Pin Input/Sense Configuration
	    // <id> pad_isc
	    // <PORT_ISC_INTDISABLE_gc"> Interrupt disabled but input buffer enabled
	    // <PORT_ISC_BOTHEDGES_gc"> Sense Both Edges
	    // <PORT_ISC_RISING_gc"> Sense Rising Edge
	    // <PORT_ISC_FALLING_gc"> Sense Falling Edge
	    // <PORT_ISC_INPUT_DISABLE_gc"> Digital Input Buffer disabled
	    // <PORT_ISC_LEVEL_gc"> Sense low Level
	    PORT_ISC_INTDISABLE_gc);

	/* set the alternate pin mux */

	I2C_Module_init();
}

void PWM_LED_initialization(void)
{

	// Set pin direction to output

	PA0_set_level(
	    // <y> Initial level
	    // <id> pad_initial_level
	    // <false"> Low
	    // <true"> High
	    false);

	PA0_set_dir(PORT_DIR_OUT);

	PWM_LED_init();
}

void PWM_0_initialization(void)
{

	// Set pin direction to output

	PF4_set_level(
	    // <y> Initial level
	    // <id> pad_initial_level
	    // <false"> Low
	    // <true"> High
	    false);

	PF4_set_dir(PORT_DIR_OUT);

	/* set the alternate pin mux */

	PORTMUX.TCBROUTEA |= PORTMUX_TCB0_bm;

	PWM_0_init();
}

/**
 * \brief System initialization
 */
void system_init()
{
	mcu_init();

	CLKCTRL_init();

	USART_NPK_initialization();

	USART_RADIO_initialization();

	SLPCTRL_init();

	CPUINT_init();

	I2C_Module_initialization();

	PWM_LED_initialization();

	PWM_0_initialization();

	BOD_init();
}

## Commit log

2024-06-07 Added programmer debugger (serial debugger)
    [ADS1115_circuit.fzz, ADXL345_circuit.fzz, AGS01DB_circuit.fzz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]
2024-07-05 small changes to how msg are sent from the board, changed potHub to work with current board and tested it with the app. Everything WORKS!
2024-07-21 ISR reading works, works with Postman. To-do: full app rework and server rework for security.
    [main.c, main.cpp]
2024-08-17 Everything functional. TODO:implement camera fucntion and user login
2024-09-06 Getting pictures work. Updated hub code a bit. Need soldi script for raspberry.Everythimg works:getting pictures, getting pot data etc.
2024-10-11 Added PCB layout
    [Buck12v-5v-TPS561208.kicad_pcb, Buck12v-5v-TPS561208.kicad_sch, SRP7028CC-6R8M.stp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]
2024-10-11 Added buck design
    [Buck12v-5v-TPS561208.kicad_pcb, Buck12v-5v-TPS561208.kicad_sch]
2024-10-12 Added new components and modules
    [12V-relay-5v-drive.kicad_pcb, 12V-relay-5v-drive.kicad_sch, 12v-SW-5v-COM.kicad_pcb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]
2024-10-13 Small new changes
    [12V-relay-5v-drive.kicad_sch, 1N4150--3DModel-STEP-711646.STEP, 1N4150.step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]
2024-10-13 Test kicad
    [Buck12v-5v-TPS561208.kicad_pcb]
2024-10-14 Added switch modules and RS485 module
    [12V-relay-5v-drive.kicad_pcb, 12V-relay-5v-drive.kicad_sch, 12v-SW-5v-COM.kicad_pcb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]
2024-10-25 Finalized the v4 of the PCB and added the web scraper test codes
    [RS485-module.kicad_pcb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]
2024-11-03 Perfected the scarping bot and added plants dir where all plants will be added as excel files
    [linksForPlants.xlsx]
2024-11-18 Added SmartPotV4 file for the new PCB. Small cghanges to the database(added new fields for plants and deleted plantId field). Big changes to the python script for webscrapping and AI. It works well. 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
    [linksForPlants.xlsx]
2025-02-28 Modified the MCU code. To do: get ready for IoT competition. This version should have working UART irq with custom handlers for irq and working-ish SPI BitBang(tested with osciloscope)
2025-03-02 Added code fro rasp zero and updated the PCB
    [LD1117S50TR.step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]
2025-03-13 Added user menu delete and working on add pot. Created Test plant and made some changes on SPI software, that might actually work.
2026-11-12 Add historical SmartPot PCB snapshot and manufacturing exports
